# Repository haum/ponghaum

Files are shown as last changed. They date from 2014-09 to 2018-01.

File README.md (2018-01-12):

# PongHaum

## Qu'est-ce que c'est ?

Ce dépôt contient les sources de ponghaum, le pong 1D réalisé par le HAUM (http://haum.org/)

## Arduino

### Présentation

Le système utilise 150 leds en bande commandées par la bibliothèque FastLED et deux boutons. Les détails du système est/sera présent sur le site du HAUM.

### Paramétrage

Le paramétrage des pins de l'arduino est réalisé dans le fichier khroma.h avec les constances PINS__*.

Par défaut, les boutons sont reliés aux entrées 2 et 3 et le bandeau de LEDs est relié à la sortie 10.
L'arduino est reliée à une alimentation ATX. Un bouton poussoir POWERSTOP (4) permet de commander l'extinction, une broche POWERCMD (5) est reliée à la commande d'allumage de l'ATX (fil vert) et une broche POWERGOOD (6) permet de détecter l'allumage de l'alimentation.

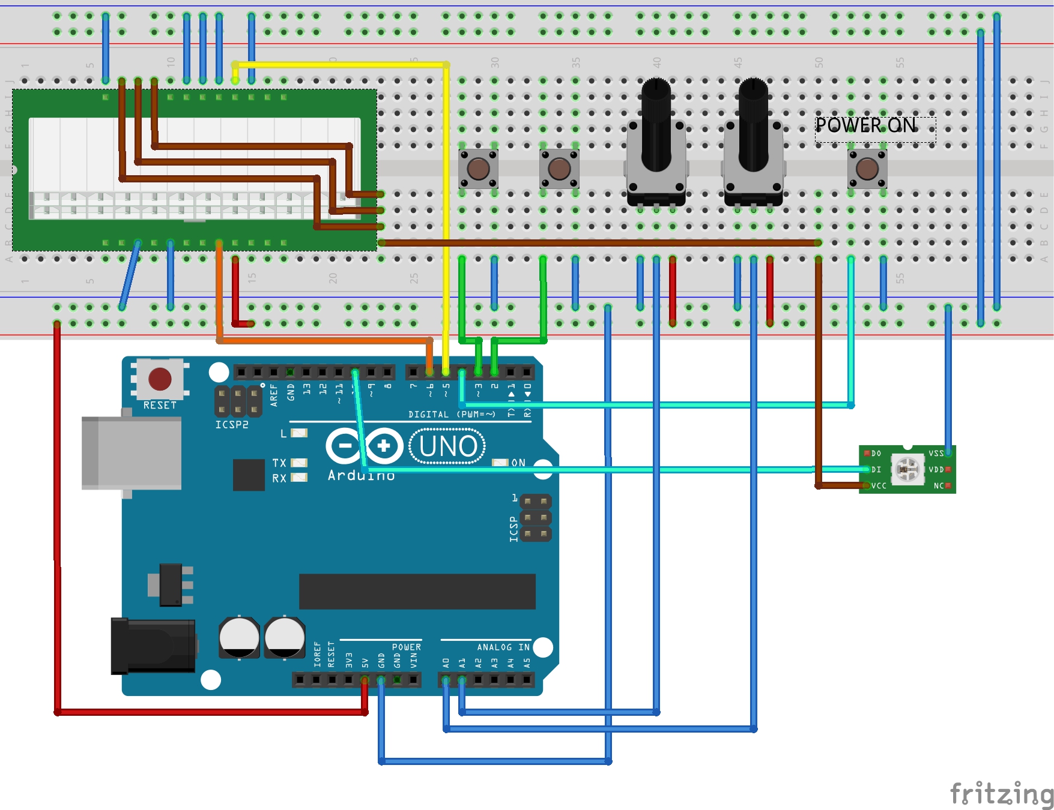
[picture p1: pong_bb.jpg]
Schéma Fritzing


### Compilation

Lorsque le dépôt est cloné, il faut penser à charger les submodules pour avoir les dépendances permettant de construire le programme pour Arduino.

```
git submodule init
git submodule update
```

Ensuite il est possible d'utiliser le Makefile pour envoyer le programme sur Arduino :

```
make upload
```

Testé avec Arduino 1.0.6

Have fun :)

## Émulateur

### Contôles

Les boutons sont émulés par des touches de calvier :

 - Flèche Gauche ou touche Q sur clavier AZERTY = bouton 1
 - Flèche Droite ou touche D sur clavier AZERTY = bouton 2

Une touche permet aussi de quitter l'émulateur :

 - Échap = Quitter l'émulateur

Les leds sont émulés par des pixels dans une fenêtre.

Les caractères envoyés sur la liaison série sont redirigés vers la sortie standard du programme.

### Raison d'être

Les sources contiennent un émulateur pour le développement et tests sur PC.

Celui-ci permet d'essayer différents programmes sans avoir accès au système électronique, en cours de construction lors de la création du dépôt.
Il faut néanmoins garder en tête que la cible principale est un microcontrôleur 8 bits avec assez peu de mémoire vive.

### Compilation

Le Makefile permet de construire l'émulateur PC (bibliothèque SDL2 nécessaire) :

```
make pc
```

Les dépendances sont seulement pthread et SDL2.

Attention, la variable d'environnement ARDUINO_DIR doit être non nulle (même si elle n'est pas rellement utilisée dans ce cas)

## Licence

Le projet est fourni sous licence MIT.

C'est une licence libre qui vous permet par exemple :
 - de le copier,
 - de l'étudier,
 - de l'adapter à vos besoins,
 - de le redistribuer

Nous vous encourageons vivement à forker et partager !

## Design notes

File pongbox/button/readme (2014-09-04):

Les fichiers de ce repertoire sont classés comme suit:

button.dxf : dessin du bouton avec le logo

ensuite deux version de bouton
1er
    button.fcstd : fichier freeCAD
    deux fichiers stl (de la base vers le haut)
        logo.stl
        bouton.stl
2eme
button2.fcstd
    deux fichiers stl (de la base vers le haut
        bouton2.stl
        logo2.stl

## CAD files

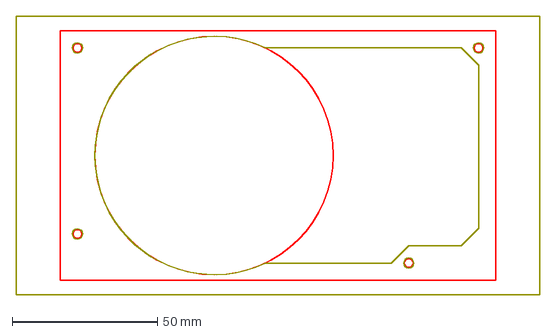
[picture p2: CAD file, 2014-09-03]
pongbox/1DPong_box/face_ar.dxf
180.0 x 96.0 mm

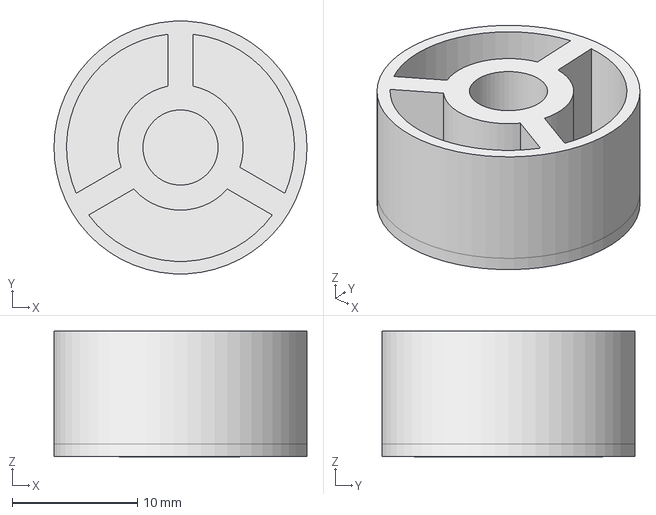
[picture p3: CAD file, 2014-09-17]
pongbox/button/button.fcstd
20.2 x 20.2 x 10.0 mm
bouton
logo (Mirror #1)001

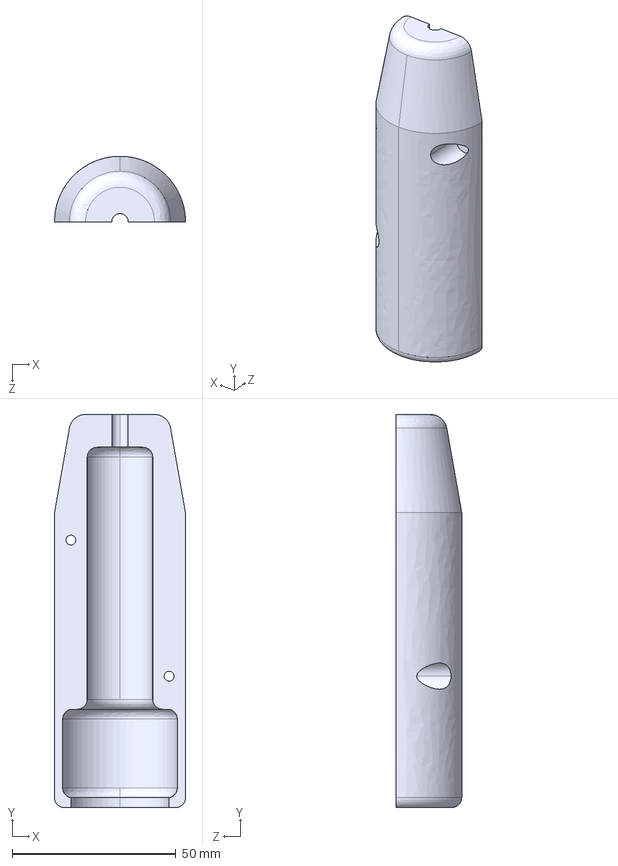
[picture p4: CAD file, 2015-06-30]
pongbox/manettes/manette.IGS
40.0 x 120.0 x 20.0 mm

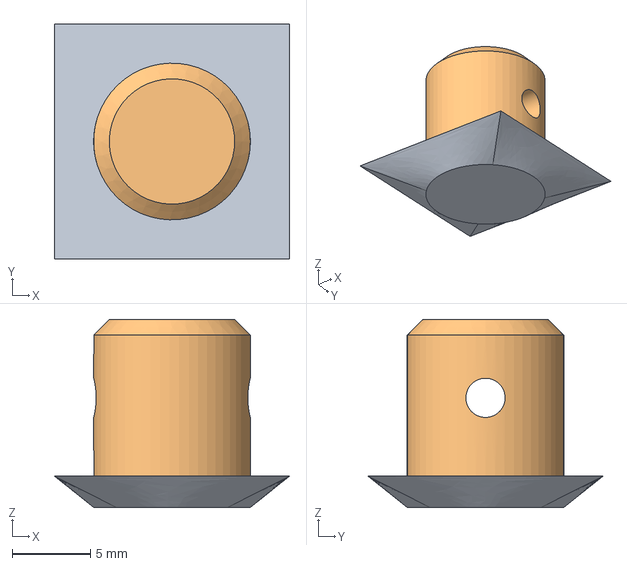
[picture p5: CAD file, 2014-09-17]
pongbox/pieds/pied.fcstd
15.0 x 15.0 x 12.0 mm
patin

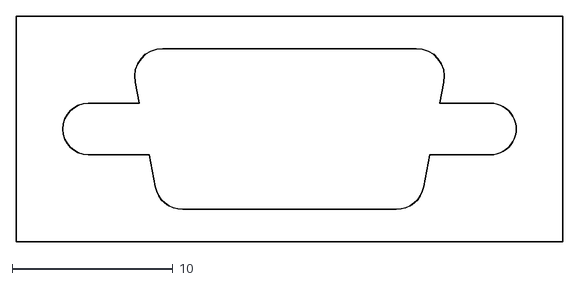
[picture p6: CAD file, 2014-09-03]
pongbox/1DPong_box/db9.dxf
34.0 x 14.0

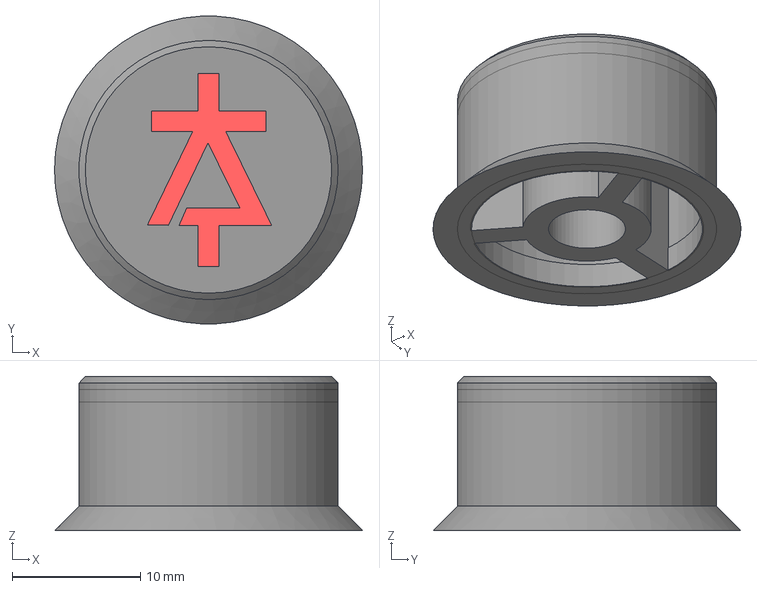
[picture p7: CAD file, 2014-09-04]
pongbox/button/button2.fcstd
24.0 x 24.0 x 12.0 mm
Ext_logo
B_final

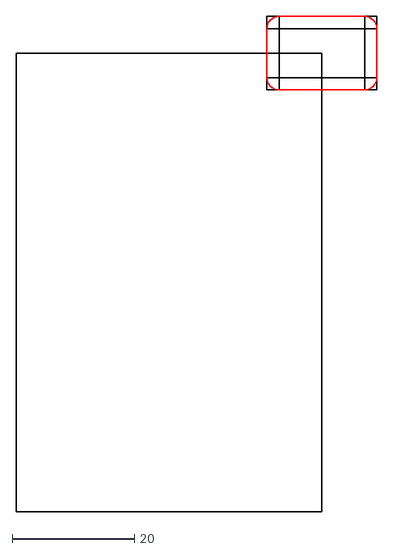
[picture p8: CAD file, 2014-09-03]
pongbox/1DPong_box/insert.dxf
59.0 x 81.0

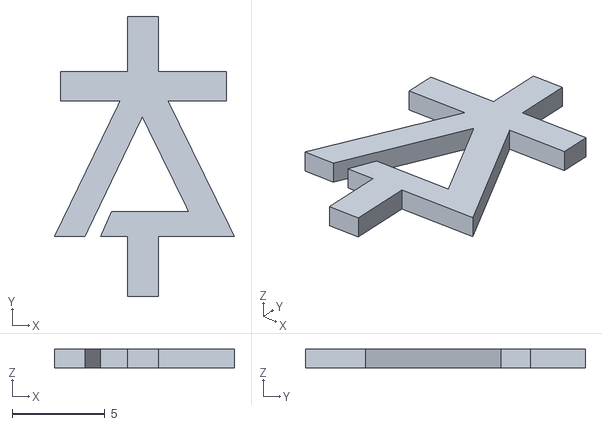
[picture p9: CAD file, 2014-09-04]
pongbox/button/logo2.stl
9.68 x 15.1 x 1.00

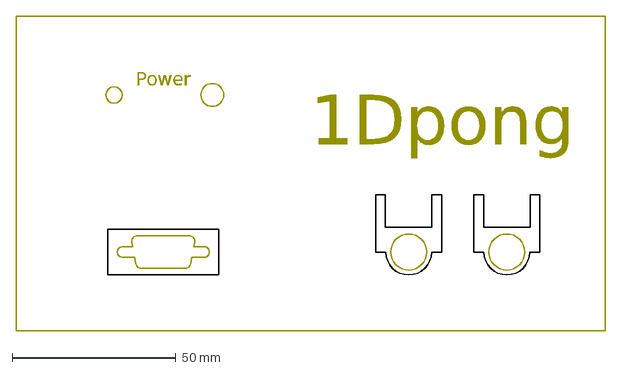
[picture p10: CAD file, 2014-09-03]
pongbox/1DPong_box/face_av.dxf
1Dpong
Power

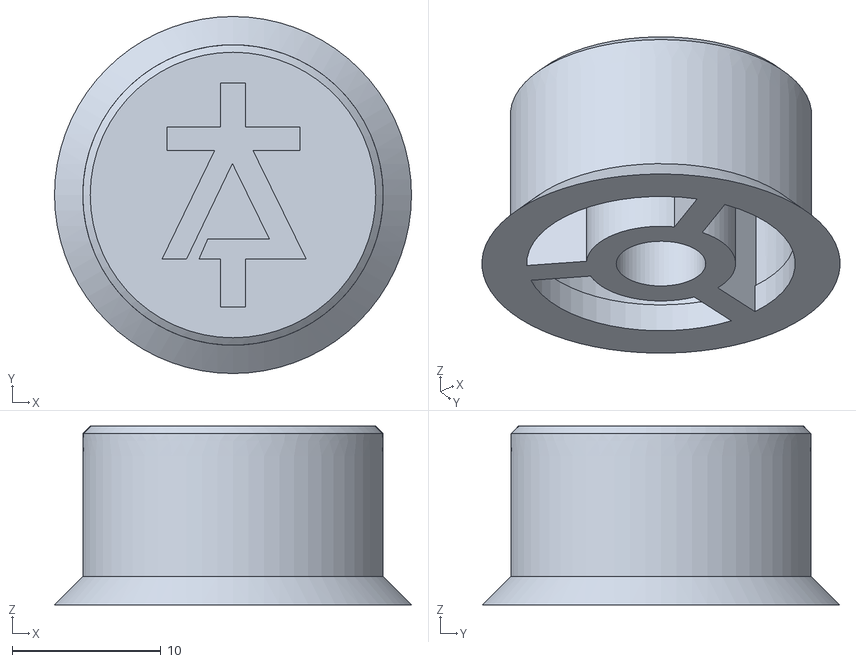
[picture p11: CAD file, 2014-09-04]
pongbox/button/bouton2.stl
24.0 x 24.0 x 12.0

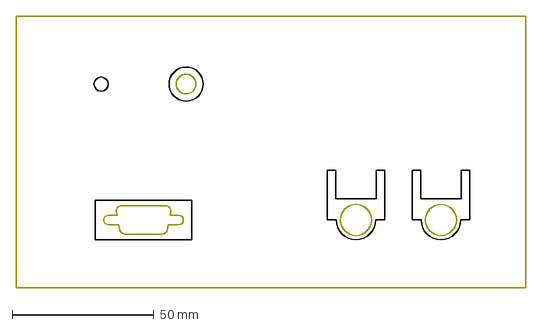
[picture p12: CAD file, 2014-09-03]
pongbox/1DPong_box/face_av-usinage.dxf
180.0 x 96.0 mm

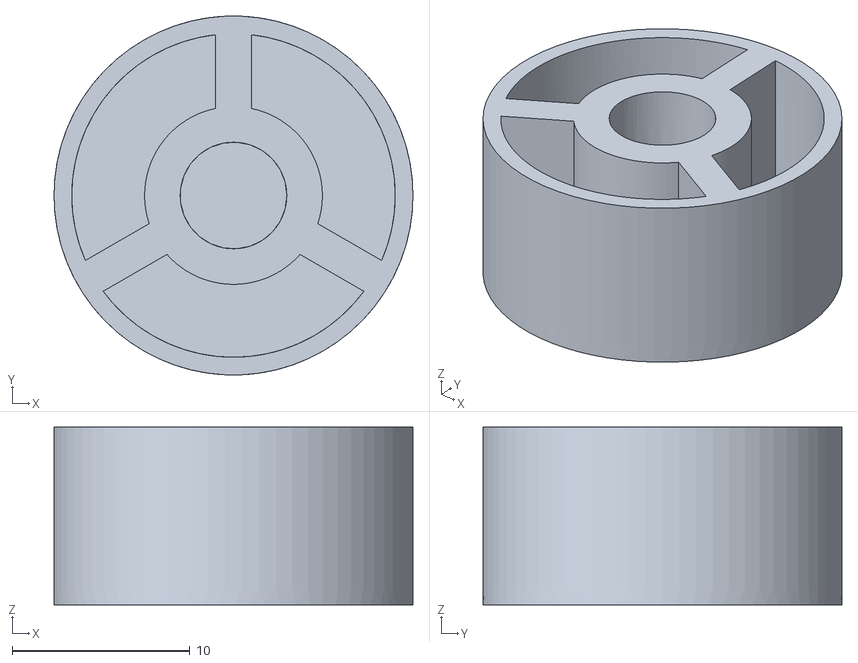
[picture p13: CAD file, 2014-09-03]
pongbox/button/bouton.stl
20.2 x 20.2 x 10.0

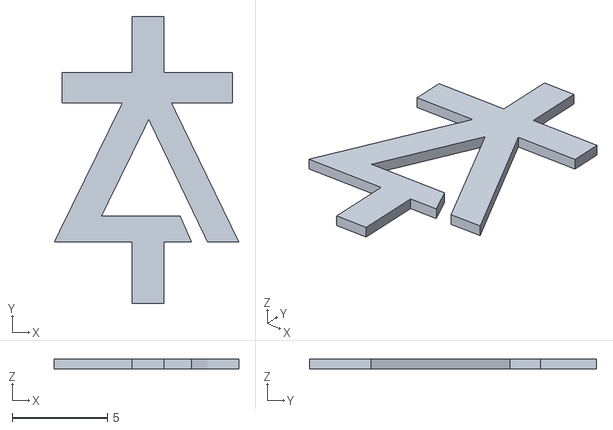
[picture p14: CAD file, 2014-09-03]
pongbox/button/logo.stl
9.68 x 15.1 x 0.5

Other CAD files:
pongbox/button/button.dxf
pongbox/manettes/manette.STL
pongbox/pieds/pied.stl

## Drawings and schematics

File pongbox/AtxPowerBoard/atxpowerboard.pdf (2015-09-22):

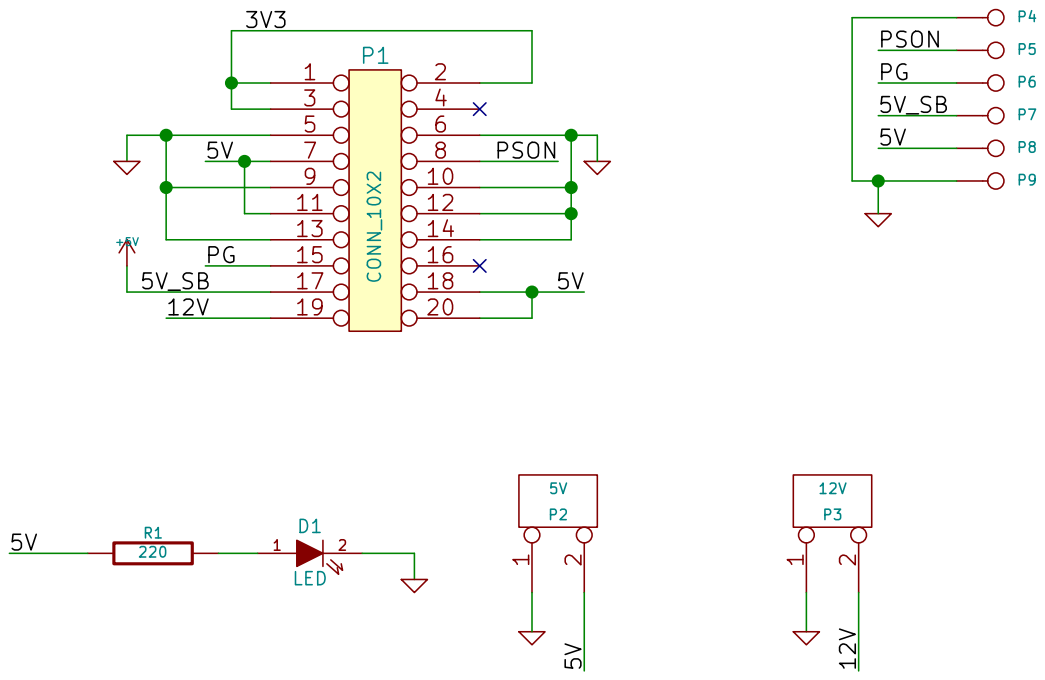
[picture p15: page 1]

File: atxpowerboard.sch Sheet: / Haum.org

Id: 1/1 Title: ATX power Board

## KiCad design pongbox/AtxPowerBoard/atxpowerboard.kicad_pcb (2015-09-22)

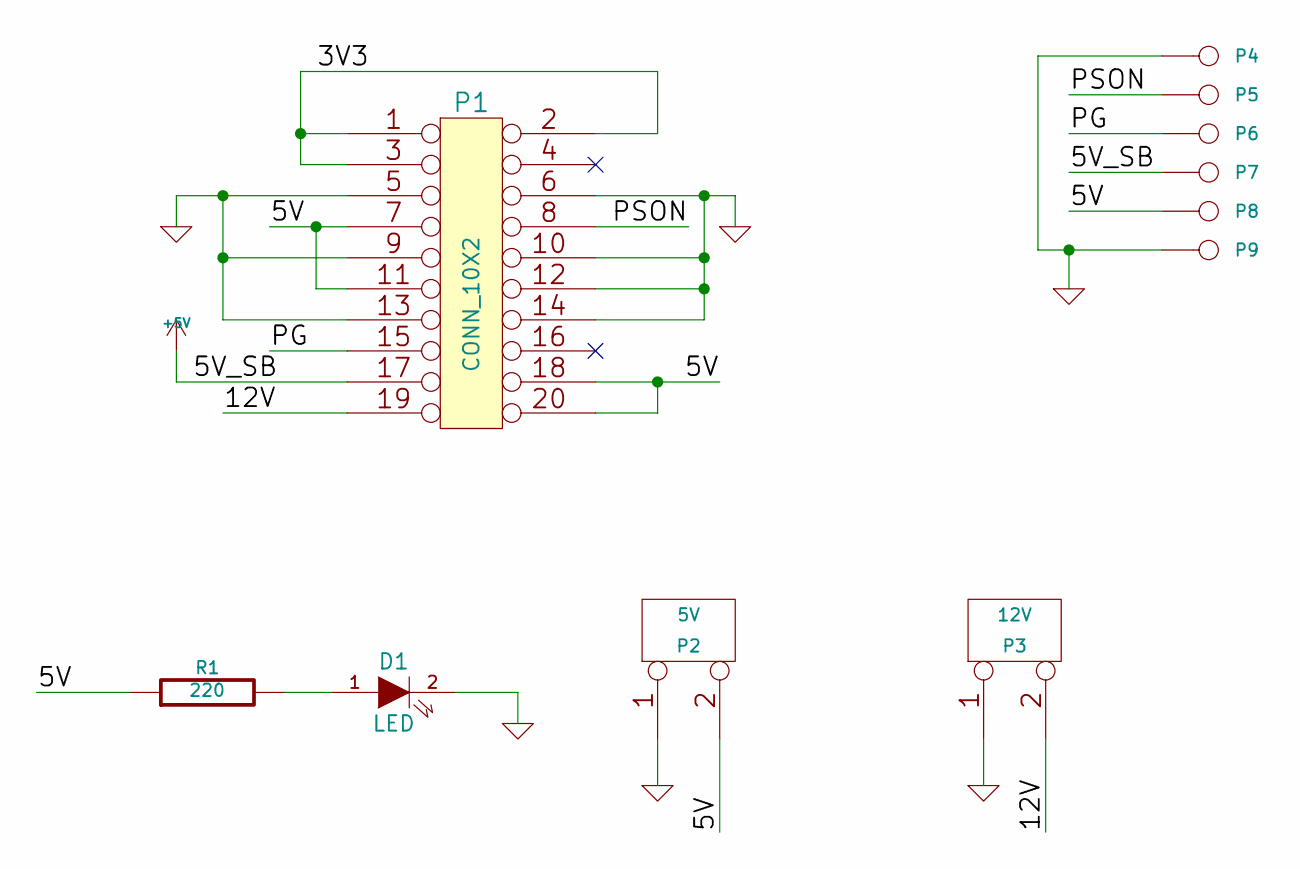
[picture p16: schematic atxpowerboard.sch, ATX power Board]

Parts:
D1: LED; LED-5MM
P1: CONN_10X2; ATX20
P2: 5V; bornier2
P3: 12V; bornier2
P4, P5, P6, P7, P8, P9: CONN_1; Pin_Header_Straight_1x01
R1: 220; Resistor_Horizontal_RM10mm

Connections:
+5V: P1.17, P7.1
/3V3: P1.1, P1.2, P1.3
/5V: P1.7, P1.11, P1.18, P1.20, P2.2 (PM), P8.1, R1.1
/12V: P1.19, P3.2 (PM)
/PG: P1.15, P6.1
/PSON: P1.8, P5.1
GND: D1.2 (K), P1.5, P1.6, P1.9, P1.10, P1.12, P1.13, P1.14, P2.1, P3.1, P4.1, P9.1
unnamed: D1.1 (A), R1.2

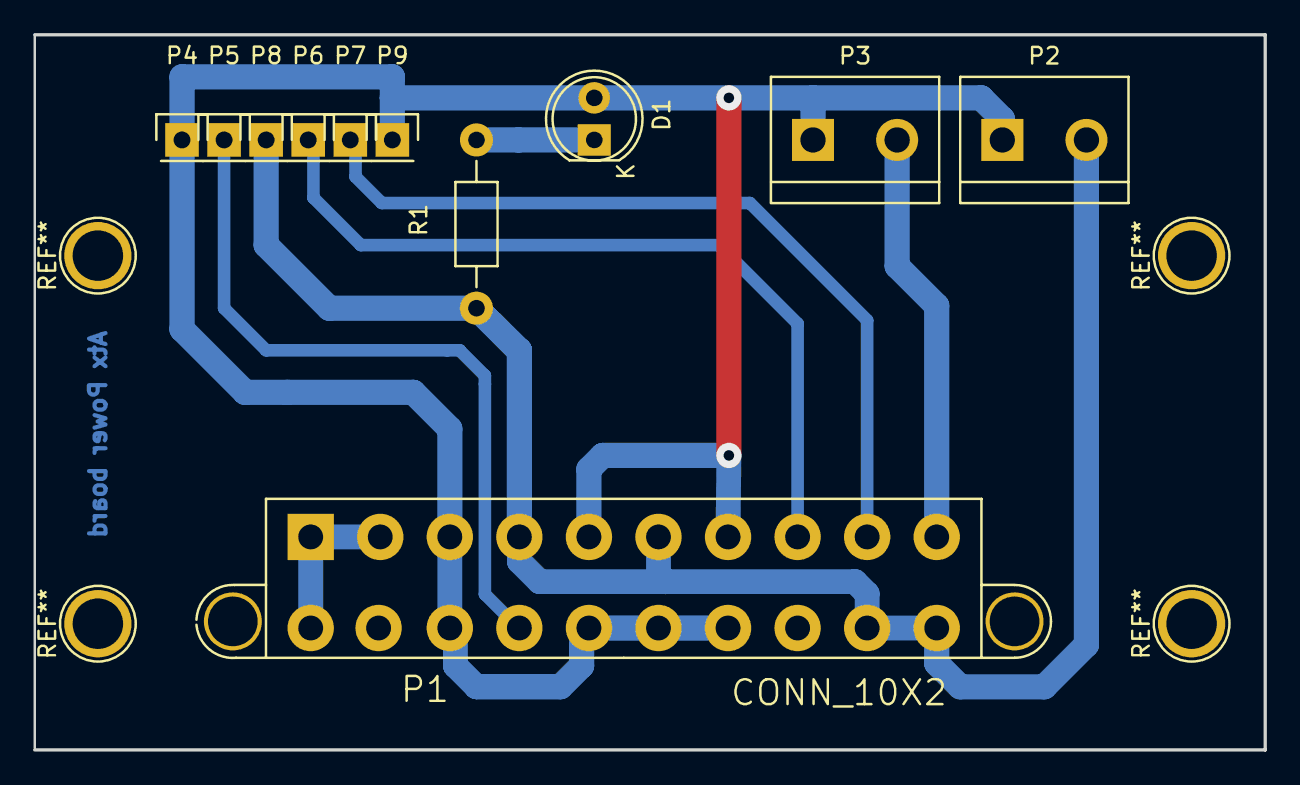
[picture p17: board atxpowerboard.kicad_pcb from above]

Board: 2 copper layers, 74.3 x 43.2 mm, 11 parts (0 on the bottom side), 8 nets.

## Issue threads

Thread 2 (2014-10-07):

Potentiomètres

JackDesBwa, 2014-10-07:
Ajouter la gestion des potentiomètres (A0, A1) dans le cœur du système.
Pas d'accès dans l'API : ils servent à ajuster la luminosité et la fréquence d'animation seulement.

jblb, 2015-07-07:
comme ce soir y avais bricodage autour du pong cen ai ou cette histoire de potentiometres

Matael, 2015-07-07:
Du coup, en posant la question à la cantonnade, on obtient une réponse ! Il s'avère que les potentiomètres sont inclus dans haum/polychrhaum mais pas dans le pong. Avis aux amateurs !

jblb, 2015-07-07:
reste donc juste a savoir comment utiliser haum/polychrhaum ;)

JackDesBwa, 2018-08-07:
Semble résolu par :
https://github.com/haum/polychrhaum/commit/b02422aa6dcf1d1ae66d12da2c020a89d8078705

Closed 2018-08-07.

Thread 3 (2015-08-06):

Imprimer les manettes pour le second pong

JackDesBwa, 2015-08-06:

MicroJoe, 2015-10-12:
Les manettes ayant été imprimées (mais utilisées dans le premier pong), est-ce qu'on envisage une seconde impression ou alors on garde les anciennes manettes pour la version "hackable" ?

sebvallee, 2015-10-12:
Je crois savoir que plusieurs jeux de manettes ont été imprimées... A vérifier auprès de @Matael...

Matael, 2015-10-12:
En effet, j'ai oublié de les descendre, mais je le ferais sous peu. Il y a deux autres manettes prêtes chez mkshp (je n'utilise pas le nom complet pour éviter l'indexation du commentaire, sorry).

Matael, 2015-10-27:
Les manettes sont (enfin) au HAUM.

Closed 2015-10-27.

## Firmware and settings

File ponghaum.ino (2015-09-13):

#include "khroma.h"
#include "game/game_manager.h"

PolychrHAUM <150, PIN__LEDSTRIP_DATA> khroma;

void animate() {
	game.animate();
}

void setup() {
	khroma.config_buttons(PIN__BTN1, PIN__BTN2);
	khroma.config_power(PIN__POWER_CMD, PIN__POWER_STATUS, PIN__POWER_BTN);
	khroma.config_light_ctrl(PIN__POTAR_LIGHT);
	khroma.config_speed_ctrl(PIN__POTAR_SPEED);
	khroma.config_animate(animate);
	khroma.setup();
	khroma.log("Bienvenue dans ponghaum !\n");
	game.init();
}

void loop() {
	khroma.loop_step();
}

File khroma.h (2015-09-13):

#ifndef KHROMA_H
#define KHROMA_H

#include <PolychrHAUM.h>

#ifdef BUILD_PC
#define A0 0
#define A1 1
#endif

#define PIN__BTN1          2
#define PIN__BTN2          3
#define PIN__POWER_BTN     4
#define PIN__POWER_CMD     5
#define PIN__POWER_STATUS  6
#define PIN__LEDSTRIP_DATA 10
#define PIN__POTAR_LIGHT   A0
#define PIN__POTAR_SPEED   A1

extern PolychrHAUM <150, PIN__LEDSTRIP_DATA> khroma;

#endif

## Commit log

2014-08-03 Add buttons click kinds
2014-08-09 Add Q and D keys to emulate buttons
2014-08-19 Link to Arduino
2014-08-20 Better Arduino makefile with submodules
2014-08-20 Ajout procédure de compilation Arduino
2014-08-20 Cleanup HMI arduino code
2014-08-20 mise a jour du README avec les instructions pour Arduino
2014-08-20 fin de ma galere de merge ....
2014-08-21 Déplacer la configuration des broches Arduino vers le Makefile
    Closes #1
2014-08-21 Mise à jour du README avec la nouvelle procédure de configuration des broches d'Arduino
2014-08-26 Ajout de broches pour la commande de l'alimentation ATX
2014-08-26 Début de l'ajout de l'écran POWEROFF
2014-08-26 Ajout des commandes ON/OFF de l'alim
2014-08-26 Gameplay: celui qui gagne relance la balle
2014-08-26 Changement du ACK sur le tableau de scores
2014-08-26 Changement des constantes de click
2014-08-26 Remplacer des événements pressed par des touched
2014-08-26 Passage des durées des animateurs en float
2014-09-01 Allongement de l'animation d'attente
2014-09-01 Retirer l'animation flicker non visible sur la balle
2014-09-01 Vitesse de départ davantage réduite pour les enfants
2014-09-01 Pour gagner, il faut pousser le score de l'autre
    Le nombre de points maxi a été réduit
2014-09-01 Faire démarrer la partie à 2 - 2
2014-09-01 Réduire le délai d'augmentation de la vitesse
2014-09-01 Dernières modifs de Mathieu
2014-09-03 fichiers d'usinage du boitier et stl boutons
    [bouton.stl, button.dxf, button.fcstd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]
2014-09-04 ajout deuxieme version bouton + readme
    [bouton2.stl, button2.fcstd, logo2.stl]
2014-09-17 modele de pieds pour la 1DPongBox
    [pied.fcstd, pied.stl]
2014-09-17 netoyage des fichiers de backup
    [button.fcstd]
2015-06-09 Ajout de modeles aux formats STL et IGS de manettes adaptées aux nouveaux boutons de 30mm.
    [manette.IGS, manette.STL]
2015-06-30 Correction des dimensions des manettes pour l'impression
    [manette.IGS, manette.STL]
2015-09-22 Ajout fichiers carte AtxPowerBoard
    [atxpowerboard.kicad_pcb, atxpowerboard.sch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]
2015-09-22 ajust dimentions de la carte
    [atxpowerboard.kicad_pcb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]
2015-09-27 Keep track of old score before modification
2015-09-27 Display a red led at the end of led strip that has triggered a double press
2016-03-15 add fritzing schematic
    [pong.fzz]
2016-03-15 fritzing schematic update
    [pong.fzz]
2016-03-26 Ajout de l'affichage de la version sur le port serie (pong) ou dans la console (emulateur)
2016-03-27 Ajout de couleur de balle différente en mode démo
2016-03-27 Modification de la couleur de la balle en fin de course
2016-03-28 Correction bug couleur sur la version PC
2017-04-30 add marker to signal where is the end of led band
2018-01-12 Link schematic image in README.md
2020-08-06 Revert "Ajout de l'affichage de la version sur le port serie (pong) ou dans la console (emulateur)"
    This reverts commit db92a7815cb98b42d3308a070497de9f49f95953.
    Useless and not in sync with actual version
    [ponghaum.ino]
2020-08-30 Add an indicator when the button stays clicked
